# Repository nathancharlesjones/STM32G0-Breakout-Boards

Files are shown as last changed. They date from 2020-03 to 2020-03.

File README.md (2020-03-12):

# STM32G031J6M6 Breakout Board
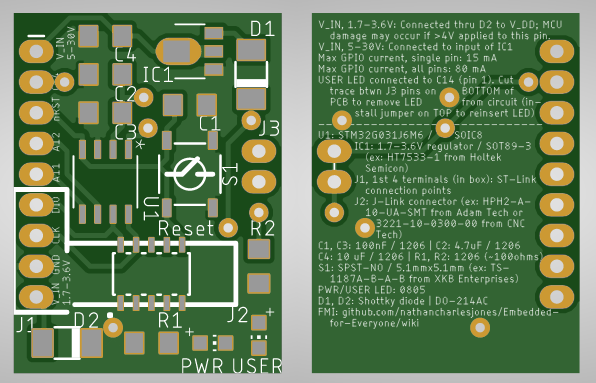
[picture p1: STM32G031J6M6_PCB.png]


# How to order
1. Download or clone this repository.
2. Follow [these instructions for ordering an assembled PCB from JLCPCB or MakerFabs](https://github.com/nathancharlesjones/Embedded-for-Everyone/wiki/3.-Building-a-circuit-on-a-PCB-and-connecting-it-to-the-rest-of-the-embedded-device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).

This board was also designed with large-enough dimensions to be manufactured by hand using a PCB mill or other manual technique. If the method you use doesn't through-plate the vias, don't forget to connect them each yourself.

# STM32G031J6M6 specifications
|Processor|Core Size|Speed|Connectivity|Peripherals|I/O|Program memory size|RAM size|Data converters|
|---|---|---|---|---|---|---|---|---|
|ARM Cortex-M0+|32-bit|64 MHz|I2C, IrDA, LINbus, SPI, UART/USART|Brown-out Detect/Reset, DMA, I2S, POR, PWM, WDT|6<sup>1</sup>|32 kB|8 kB|ADC: 8x 12-bit|

Notes:
1. Of the 6 GPIO this MCU supposedly has, one is used for reset and two are used for the SWD interface, meaning this MCU, realistically, only has 3 GPIO.

# Schematic
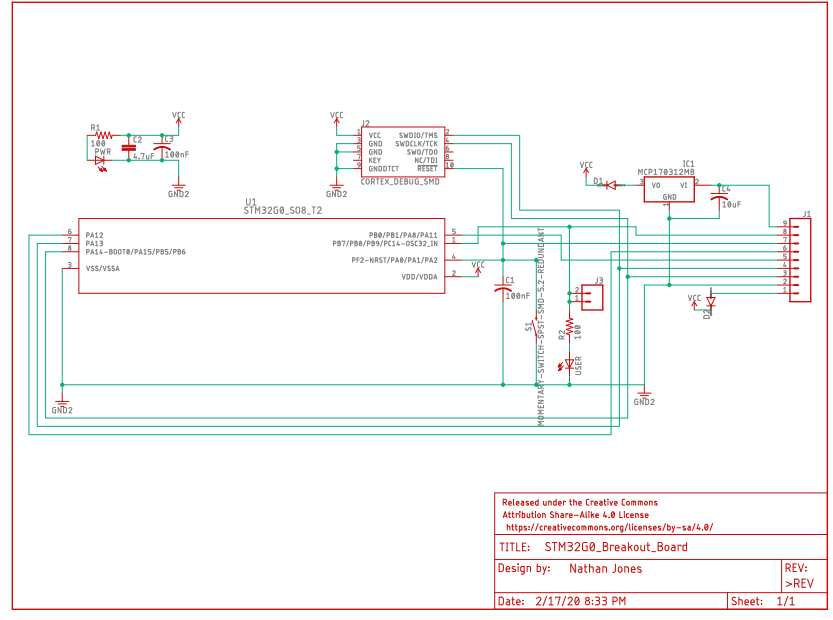
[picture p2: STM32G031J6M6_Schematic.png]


The schematic for this breakout board includes 5 modules or sections:
1. MCU
   - The MCU itself and the 0.1" pin header to which most of the MCU pins are connected (U1 and J1).
2. Power 
   - Power regulator, power filtering capacitors, and an LED indicator (IC1, D1, D2, C2, C3, C4, PWR LED, and R1).
   - Only C2 and C3 are technically required for MCU operation. If you decide to only include those two components, don't forget to bridge the pads of D2.
   - If IC1 is used, D1 and D2 are strongly recommended, though not technically required. D1 and D2 allow for the MCU to be powered from both the VIN_1.7-3.6V and VIN_5-30V pins at the same time without them damaging each other.
3. Reset
   - The reset button and smoothing capacitor (S1 and C1).
4. User LED
   - LED, current-limiting resistor, and option jumper (USER LED, R2, and J3)
   - J3 is used to optionally remove the LED from the circuit, should you wish to not have the LED connected to its GPIO.
   - To remove LED2 from the circuit, cut the trace between the terminals of J3 on BOTTOM of the PCB (where its marked on the silkscreen).
   - To reinsert USER LED, place a pin header and jumper in J3. The jumper now controls whether USER LED is included in the circuit or not.
5. J-Link connector (J2)

The cost is approximately $3.30 per board on JLCPCB (in quantities of 10).

# PCB Silkscreen Text
> - V_IN, 1.7-3.6V: Connected thru D2 to V_DD; MCU damage may occur if >4V applied to this pin.
> - V_IN, 5-30V: Connected to input of IC1
> - Max GPIO current, single pin: 15 mA
> - Max GPIO current, all pins: 80 mA
> - USER LED connected to C14 (pin 1). Cut trace btwn J3 pins on BOTTOM of PCB to remove LED from circuit (in-stall jumper on TOP to reinsert LED)
> ------------------------------
> - U1: STM32G031J6M6 / SOIC8
> - IC1: 1.7-3.6V regulator / SOT89-3 (ex: HT7533-1 from Holtek Semicon)
> - J1, 1st 4 terminals (in box): ST-Link connection points
> - J2: J-Link connector (ex: HPH2-A-10-UA-SMT from Adam Tech or 3221-10-0300-00 from CNC Tech)
> - C1, C3: 100nF / 1206  | C2: 4.7uF / 1206
> - C4: 10 uF / 1206      | R1, R2: 1206 (~100ohms)
> - S1: SPST-NO / 5.1mmx5.1mm (ex: TS-1187A-B-A-B from XKB Enterprises)
> - PWR/USER LED: 0805
> - D1, D2: Shottky diode | DO-214AC
> - FMI: github.com/nathancharlesjones/Embedded-for-Everyone/wiki

# References
- [STM32G031J6 product page](https://www.st.com/content/st_com/en/products/microcontrollers-microprocessors/stm32-32-bit-arm-cortex-mcus/stm32-mainstream-mcus/stm32g0-series/stm32g0x1/stm32g031j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)
- [AN5096, Getting started with STM32G0 series hardware development](https://www.st.com/resource/en/application_note/dm00443870.pdf)
- [DS12992](https://www.st.com/resource/en/datasheet/stm32g031j6.pdf), STM32G031J6M6 datasheet
- [RM0444](https://www.st.com/resource/en/reference_manual/dm00371828.pdf), STM32G031J6M6 reference manual

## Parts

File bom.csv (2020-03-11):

Comment | Designator | Footprint | LCSC Part #（optional）
100nF | C1,C3 | 1206_C | C24497
4.7uF | C2 | 1206_C | C29823
10uF | C4 | 1206_C | C13585
 | D1,D2 | DO-214AC | C2480
3.3V | IC1 | SOT-89-3 | C14289
 | PWR,USER | 0805 | C84256
100Ω | R1, R2 | 1206_R | C17901
 | S1 | 5.1mmx5.1mm | C318884
 | U1 | SOIC-8 | C432201

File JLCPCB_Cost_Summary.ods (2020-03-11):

Setup fee | $7.00
Stencil | $1.50
Extended parts | $6.00
Coupon? | -$7.00
Parts | $1.45
Soldering | $0.05 | 36 | 0.0015
PCB qty |  | Total cost | Cost/PCB
5 | $4.00 | $26.02 | $5.20
10 | $5.00 | $27.54 | $2.75
15 | $14.10 | $44.16 | $2.94
20 | $17.40 | $54.98 | $2.75
25 | $20.80 | $65.90 | $2.64
30 | $24.10 | $76.72 | $2.56
50 | $36.30 | $119.00 | $2.38

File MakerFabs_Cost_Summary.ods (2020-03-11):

Stencil fee | $18.00
Parts | $1.85
Soldering | $1.08 | 36 | 0.03
PCB qty |  | Total cost | Cost/PCB
5 | $4.90 | $37.55 | $7.51
10 | $4.90 | $52.20 | $5.22
20 | $16.75 | $93.35 | $4.67
50 | $29.50 | $194.00 | $3.88

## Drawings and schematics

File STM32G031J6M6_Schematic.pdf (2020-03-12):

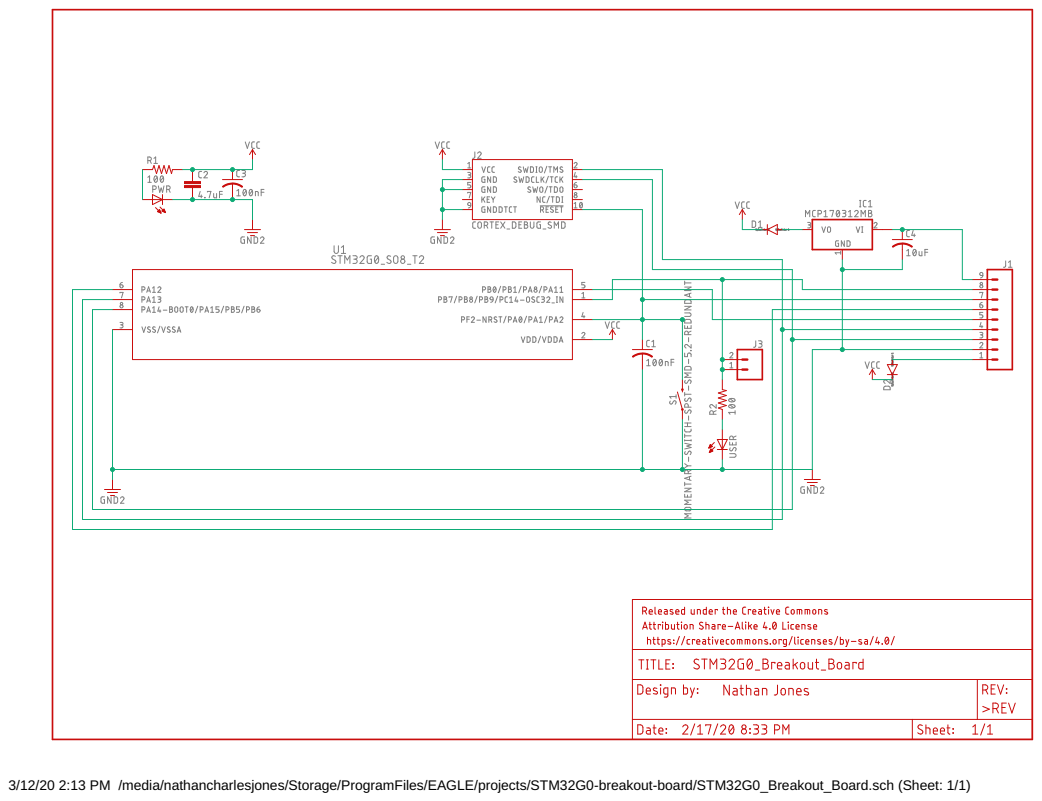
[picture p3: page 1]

3/12/20 2:13 PM /media/nathancharlesjones/Storage/ProgramFiles/EAGLE/projects/STM32G0-breakout-board/STM32G0_Breakout_Board.sch (Sheet: 1/1)

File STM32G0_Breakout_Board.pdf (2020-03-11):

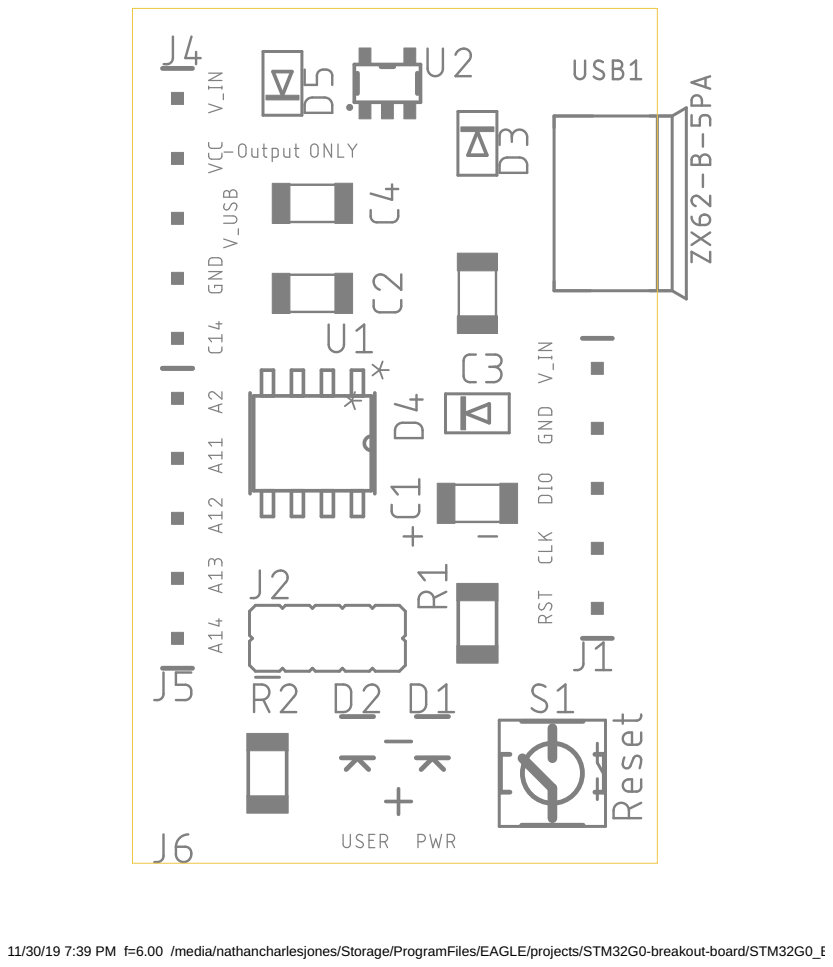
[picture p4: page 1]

11/30/19 7:39 PM f=6.00 /media/nathancharlesjones/Storage/ProgramFiles/EAGLE/projects/STM32G0-breakout-board/STM32G0_Breakout_Board.brd

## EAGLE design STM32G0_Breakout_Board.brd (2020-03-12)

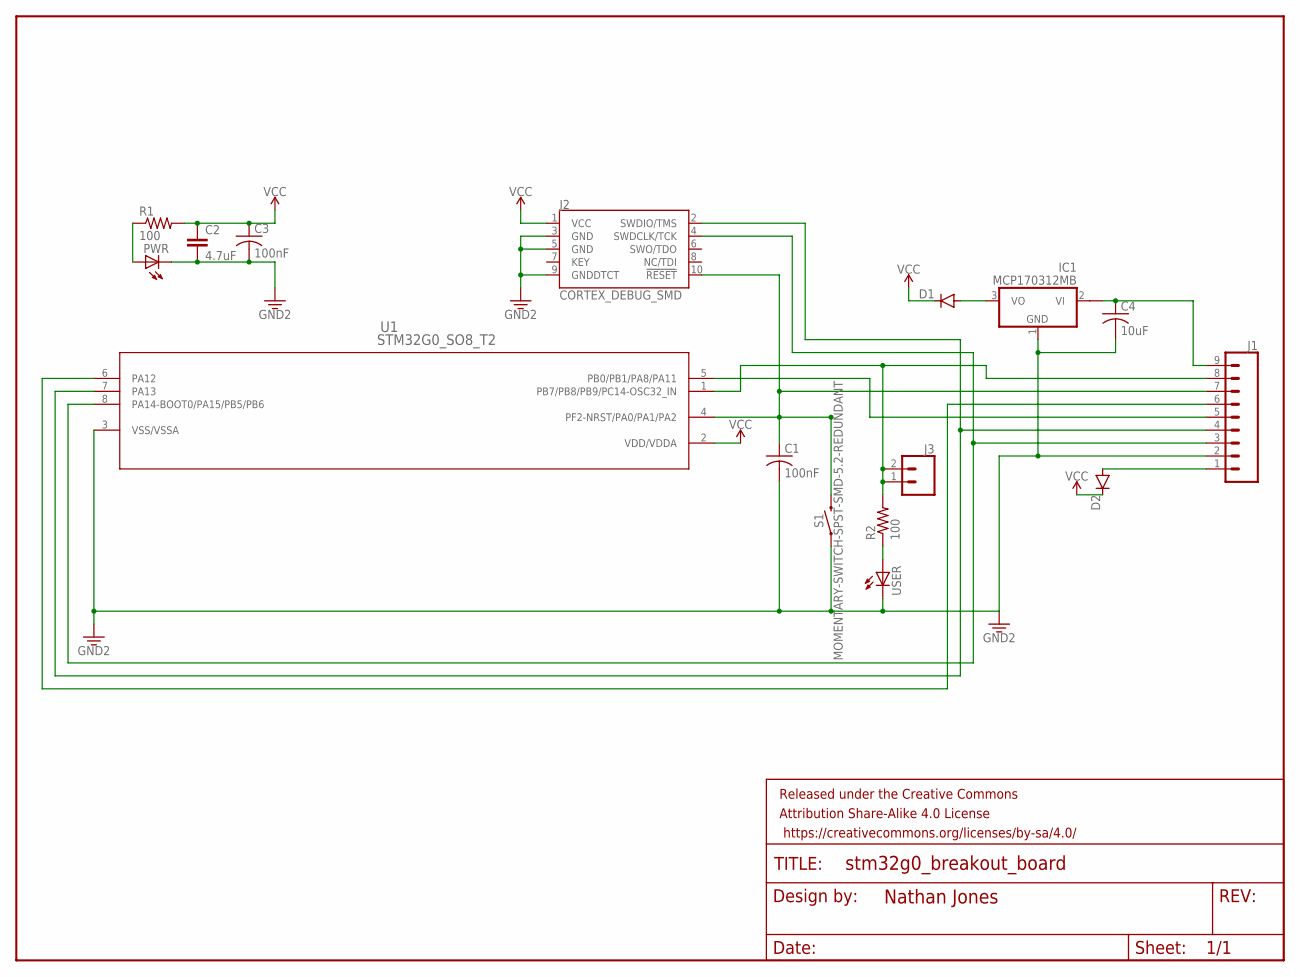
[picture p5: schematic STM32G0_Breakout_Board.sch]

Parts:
C1, C3: 100nF; C1206
C2: 4.7uF; 1206
C4: 10uF; C1206
D1, D2: DIODE-DO-214AC; DO-214AC
FRAME1: FRAME-LETTERNO_PACKAGE; DUMMY
IC1: MCP170312MB; SOT89
J1: CONN_09LONGPADS; 1X09_LONGPADS
J2: CORTEX_DEBUG_SMD; SAMTECH_FTSH-105-01
J3: CONN_02PTH3; 1X02_LONGPADS
PWR: LEDCHIP-LED0805; CHIP-LED0805
R1, R2: 100; R1206
S1: MOMENTARY-SWITCH-SPST-SMD-5.2-REDUNDANT; TACTILE_SWITCH_SMD_5.2MM
U1: STM32G0_SO8_T2; SO-8
USER: LEDCHIP-LED0805; CHIP-LED0805

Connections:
GND: C1.2, C2.2, C3.2, C4.2, IC1.1 (GND), J1.2, J2.3 (GND), J2.5 (GND), J2.9 (GNDDTCT), PWR.C, S1.1, S1.2 (1), U1.3 (VSS/VSSA), USER.C
unnamed: R2.1, USER.A
unnamed: D2.A, J1.1
unnamed: C4.1, IC1.2@1 (VI1), J1.9
unnamed: PWR.A, R1.1
unnamed: D1.A, IC1.3 (VO)
NRST/PA0/PA1/PA2: C1.1, J1.7, J2.10 (!RESET), S1.3 (2), S1.4 (2), U1.4 (PF2-NRST/PA0/PA1/PA2)
PA12: J1.6, U1.6 (PA12)
PB0/PB1/PA8/PA11: J1.5, U1.5 (PB0/PB1/PA8/PA11)
PC14: J1.8, J3.1, J3.2, R2.2, U1.1 (PB7/PB8/PB9/PC14-OSC32_IN)
SWDCLK: J1.3, J2.4 (SWDCLK/TCK), U1.8 (PA14-BOOT0/PA15/PB5/PB6)
SWDIO: J1.4, J2.2 (SWDIO/TMS), U1.7 (PA13)
VCC: C2.1, C3.1, D1.C, D2.C, J2.1 (VCC), R1.2, U1.2 (VDD/VDDA)

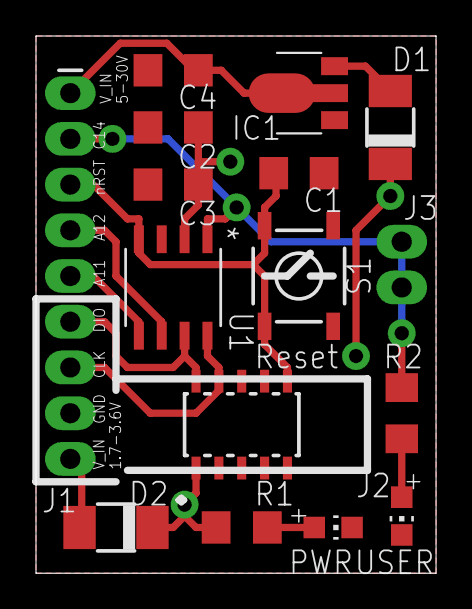
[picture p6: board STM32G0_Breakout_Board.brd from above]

Board: 2 copper layers, 22.2 x 29.8 mm, 17 parts (0 on the bottom side), 13 nets.

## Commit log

2020-03-11 First commit.
    [JLCPCB_Cost_Summary.ods, MakerFabs_Cost_Summary.ods, STM32G0_Breakout_Board.brd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]
2020-03-12 Updated README. Added schematic (PNG and PDF) and PCB (PNG).
    [STM32G0_Breakout_Board.brd]

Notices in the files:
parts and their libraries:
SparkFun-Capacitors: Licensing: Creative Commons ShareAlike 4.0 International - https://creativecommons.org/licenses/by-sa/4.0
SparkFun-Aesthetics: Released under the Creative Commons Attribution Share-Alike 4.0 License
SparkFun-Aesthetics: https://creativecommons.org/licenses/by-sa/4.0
